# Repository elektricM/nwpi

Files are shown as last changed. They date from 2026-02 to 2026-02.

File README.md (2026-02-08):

# NWPi - NumWorks Pi Power Module

Power module PCB for running a Raspberry Pi Zero inside a NumWorks calculator.

## Specs
- **Input:** USB 5V 1A
- **Battery:** 3.7V LiPo (TP4056 charger, 600mA)
- **Output:** 5V 1.5A (SX1308 boost)
- **Size:** 19 × 20.5mm

## Components
- TP4056 - LiPo charger IC
- SX1308 - Boost converter
- SS34 - Schottky diode
- 4.7µH inductor

## Files
- `nwpi.kicad_sch` - Schematic
- `nwpi.kicad_pcb` - PCB layout
- `production/` - Gerbers for JLCPCB

## License
MIT

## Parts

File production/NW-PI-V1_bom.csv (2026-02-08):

Designator | Footprint | Quantity | Value | LCSC Part #
C1 | 0603 | 1 | 10u
C2 | 0805 | 1 | 22u
C3, C4 | 0603 | 2 | 4.7u
D1 | SMA_L4.3-W2.6-LS5.2-RD | 1 | SS34_C8678
J1 | WiredPad_3x2mm | 1 | VUSB
J2 | WiredPad_3x2mm | 1 | GND
J3 | WiredPad_3x2mm | 1 | VBAT
J4 | WiredPad_3x2mm | 1 | 5V_PI
J5 | WiredPad_3x2mm | 1 | PI_EN
J6 | WiredPad_3x2mm | 1 | CHG_STAT
L1 | IND-SMD_L4.0-W4.0_SMNR4020 | 1 | SMNR4020-4R7MT | C467061
R1 | 0402 | 1 | 2k
R2 | 0603 | 1 | 30k
R3 | 0603 | 1 | 220k
R4 | 0402 | 1 | 10k
U1 | ESOP-8_L4.9-W3.9-P1.27-LS6.0-BL-EP | 1 | TP4056
U2 | SOT-23-6_L2.9-W1.6-P0.95-LS2.8-BL | 1 | SX1308

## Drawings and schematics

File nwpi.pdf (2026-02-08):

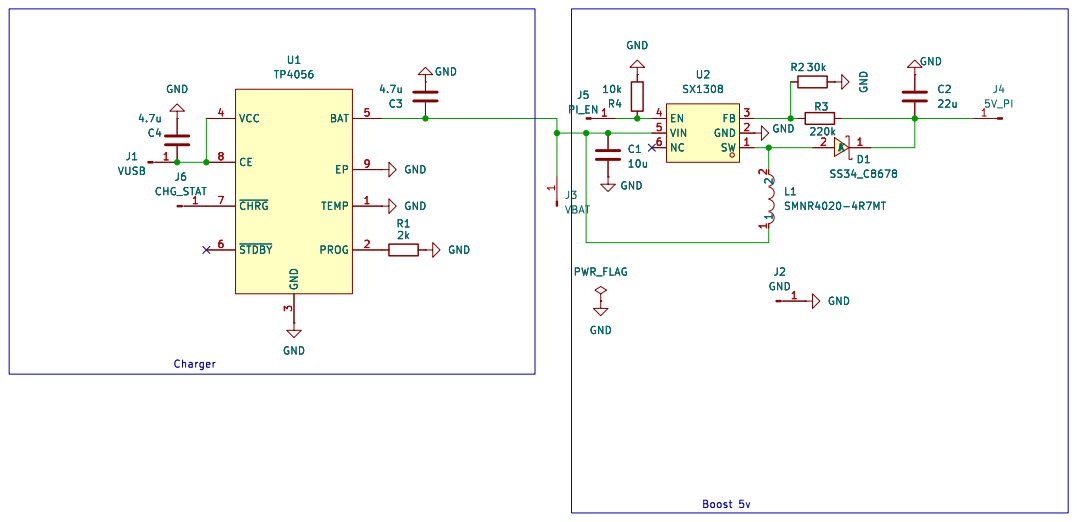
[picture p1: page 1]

3 BAT 5 EP 9 TEMP 1 PROG 2 U1 TP4056 GND GND GND

3 BAT 5 EP 9 TEMP 1 PROG 2 GND GND

4.7u GND 4.7u GND 2kGND 2kGND R1 R1

10k PWR_FLAG

Id: 1/1 Title: NumWorks-pi-adapter File: nwpi.kicad_sch Sheet: / MARTIN

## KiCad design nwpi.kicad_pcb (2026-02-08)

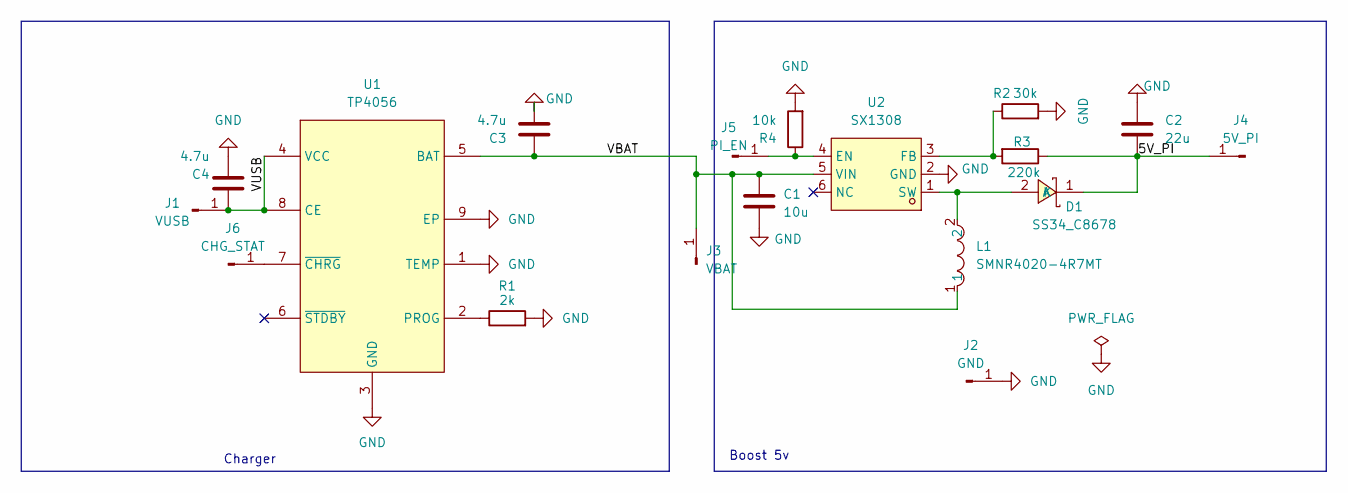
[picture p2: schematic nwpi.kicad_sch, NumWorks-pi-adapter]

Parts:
C1: 10u; C_0603_1608Metric
C2: 22u; C_0805_2012Metric
C3, C4: 4.7u; C_0603_1608Metric
D1: SS34_C8678; SMA_L4.3-W2.6-LS5.2-RD; LCSC Part C8678
J1: VUSB; WiredPad_3x2mm
J2: GND; WiredPad_3x2mm
J3: VBAT; WiredPad_3x2mm
J4: 5V_PI; WiredPad_3x2mm
J5: PI_EN; WiredPad_3x2mm
J6: CHG_STAT; WiredPad_3x2mm
L1: SMNR4020-4R7MT; IND-SMD_L4.0-W4.0_SMNR4020; LCSC Part C467061
R1: 2k; R_0402_1005Metric
R2: 30k; R_0603_1608Metric
R3: 220k; R_0603_1608Metric
R4: 10k; R_0402_1005Metric
U1: TP4056; ESOP-8_L4.9-W3.9-P1.27-LS6.0-BL-EP; LCSC Part C16581
U2: SX1308; SOT-23-6_L2.9-W1.6-P0.95-LS2.8-BL; LCSC Part C78162

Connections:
/5V_PI: C2.1, D1.1 (K), J4.1, R3.1
/VBAT: C1.1, C3.1, J3.1, L1.1, U1.5 (BAT), U2.5 (VIN)
/VUSB: C4.1, J1.1, U1.4 (VCC), U1.8 (CE)
GND: C1.2, C2.2, C3.2, C4.2, J2.1, R1.2, R2.2, R4.2, U1.1 (TEMP), U1.3 (GND), U1.9 (EP), U2.2 (GND)
unnamed: D1.2 (A), L1.2, U2.1 (SW)
unnamed: J5.1, R4.1, U2.4 (EN)
unnamed: J6.1, U1.7 (~CHRG)
unnamed: R1.1, U1.2 (PROG)
unnamed: R2.1, R3.2, U2.3 (FB)

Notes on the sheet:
Charger
Boost 5v

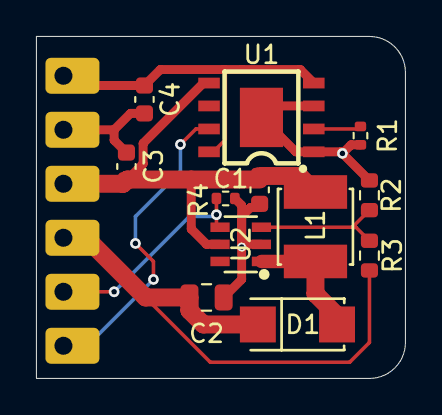
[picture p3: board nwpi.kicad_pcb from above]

Board: 2 copper layers, 20.5 x 19.0 mm, 18 parts (0 on the bottom side), 9 nets.
